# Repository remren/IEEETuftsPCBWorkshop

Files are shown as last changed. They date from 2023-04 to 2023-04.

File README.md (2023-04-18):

# IEEETuftsPCBWorkshop
An introductory PCB workshop for the Tufts IEEE club using KiCad 7.0. The basis for this workshop is making a keyboard PCB, following these guides: [Masterzen's Guide](https://www.masterzen.fr/2020/05/03/designing-a-keyboard-part-1/) and [ai03's Guide](https://wiki.ai03.com/books/pcb-design/page/pcb-guide-part-1---preparations)

By learning how to make this PCB, hopefully one will be able use knowledge for other personal or work projects!

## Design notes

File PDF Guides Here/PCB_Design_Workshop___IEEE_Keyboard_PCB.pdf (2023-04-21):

# PCB Design Workshop - Tufts IEEE Keyboard PCB

Remy Ren

March 2023

## 1 Before You Attend: DOWNLOAD KiCad 7.0

https://www.kicad.org/download/

1. Do this before coming to the workshop as it’s a 1 GB download for just the installer. KiCad is neat because it is OPEN SOURCE AND FREE!
2. Other PCB design tools exist, such as Altinum, EAGLE, EasyEDA, etc. but KiCad is a great starter.

## Optional: Git/Github Primer

Git/Github is a great solution for keeping track of files (version history), storing files, and collaboration.

If enough people want, I’ll go over a really basic primer on Git/Github using a command line interface (Terminal, Windows PowerShell, MobaXterm, etc.).

If you want to follow along or do this in your own time, the primer I’ll be giving can be found here:

https://bit.ly/Git-GithubPrimer

## 2 Starting Interface

1. Create a new folder in a place of your choice to put your project in. If you used Git/Github, make this new folder within where you cloned your repository.
2. In KiCad, click Create new blank project (CTRL+N), name it and save it to the folder you just made. We start with the Schematic Editor (CTRL+E) first.

1

3. We’ll need additional footprint libraries to use keyboard switches and USB-C ports. Either download the ZIP to each repository or add them as submodules in your repository:

https://github.com/ai03-2725/MX_Alps_Hybrid.githttps://github.com/ai03-2725/Type-C.pretty.githttps://github.com/ai03-2725/random-keyboard-parts.pretty.git

4. In Preferences → Manage Symbol Libraries and add the three libraries by clicking on the folder icon and adding the .lib file in the folders (may be nested within Schematic Folder ). Then, in Preferences → Manage Footprint Libraries, select all folders which have a .pretty at the end of its name.

## 3 Building the Schematic: Microcontroller Unit

1. We will be using the Atmega32U4 as our microcontroller of choice.
2. To add the component, press (A) or goto the right sidebar and select the op-amp icon. Give the interface some time to load!
3. Search atmega32u4 and select ATmega32U4-A (not -M as its pins are on the bottom of the package). Place it on the schematic by clicking within the space.
(a) The datasheet for this MCU: http://ww1.microchip.com/downloads/

en/devicedoc/atmel-7766-8-bit-avr-atmega16u4-32u4_datasheet.pdf (http://ww1.microchip.com/downloads/en/devicedoc/atmel-7766-8-bit-avr-atmega16u4-32u4_datasheet.pdf)
(b) We’ll be following this schematic to layout components for the MCU:

2

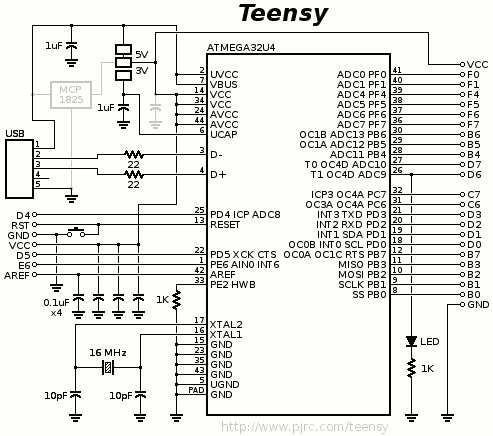
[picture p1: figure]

Figure 1: PJRC Teensy Schematic for the ATmega32U4-A

4. Let’s first add power/ground to the MCU. Press (P) or select the ground icon on the right sidebar, searching for: 5v. Select it and place it above the top of the MCU.
5. UVCC, VCC, AVCC all need to be connected to this +5V. To place wires and connect them, press (W) or the gray line icon on the right sidebar. Add another +5V component for VCC.
6. To place the ground, again press (P), search for GND and place it at the bottom of the MCU and cwonnect UGND, GND to GND.
7. The HWB/PE2 requires a pull-down resistor (needs to be connected to ground). Hit (A) and search for R or R Small (preferred). Add another ground and connect the resistor to it.

To exit any current action mode, press (ESC). If you want to rotate the component, press (R) while it is selected. To move a component, select and press (M).

8. Double-click on the R or R Small to edit its value and set it to 10k (discrepancy with Teensy schematic).
9. UCAP is the voltage regulator for the internal USB pins. It requires a 1µF (type 1u) capacitor according to the datasheet. Add a C Small to the pin and connect it to a new ground component.
10. AREF which is responsible for analog signals doesn’t need to be wired, so mouse over the pin and press (Q) to mark it with a cross.

3

11. Next, we’ll work with labels. These allow you to connect components together by name association instead of wires. There are two labels within KiCad: global or net class directive. Using either is OK in this demo, but if you were to use a multi-level/layer PCB, global is the preferred option.
12. To add a global label, press CTRL+L or click on the “tag” looking icon with an A inside.
13. Add a global label to XTAL1 naming it XTAL1, then do the same for XTAL2. To flip a component, press (X).
14. Add a global label the same way for D+, D-.
15. Next, we’ll be working to add an external clock for the MCU. Elsewhere on the board, place a global label for XTAL1, XTAL2.
16. The circuit for the external clock uses a 16MHz crystal oscillator (search Crystal GND24 small and two 22pF capacitors. Connect them to the global labels like this:

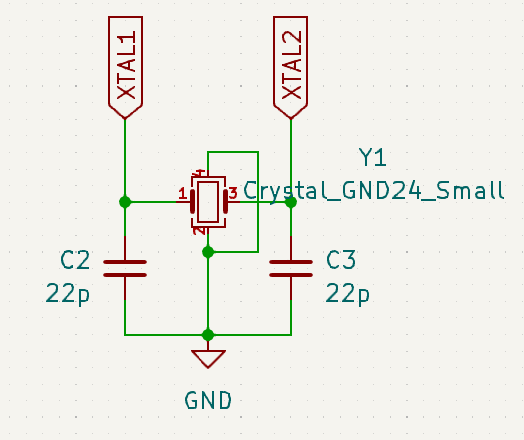
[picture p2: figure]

Figure 2: Schematic for XTAL

17. We need to add a set of decoupling capacitors for the MCU. The datasheet recommends a 0.1µF for each VCC pin (2xUVCC, 2xVCC, AVCC). One of the capacitors is shared between UVCC and VBUS instead of adding an additional one. We can make our schematic neater by using a +5V component to connect the capacitors like in the following:

4

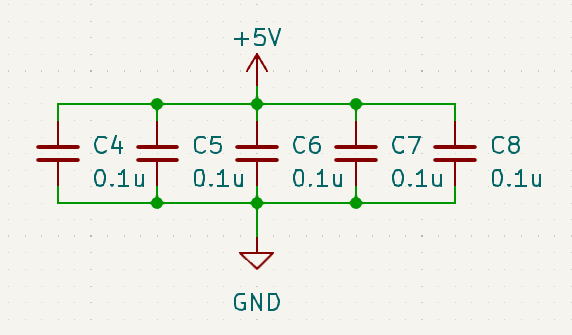
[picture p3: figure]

Figure 3: Schematic for Coupling Capacitors

Press (CTRL+C) and (CTRL+V) to copy/paste a component instead of entering it multiple times.

18. We will add a set of ISP header pins to access the MCU in event of catastrophic failure. This will allow us to reprogram the MCU with the Serial Peripheral Interface (SPI) and the ISP programming mode. (https://docs.qmk.fm/#/isp_flashing_guide)
(a) First, add a global label like we did earlier for MISO, MOSI, SCK. Connect them like this to the MCU:

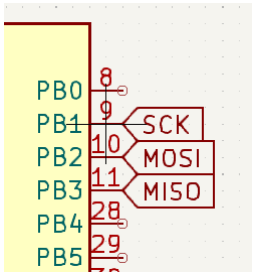
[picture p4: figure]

Figure 4: Global Labels for ISP to MCU

(b) Add a AVR-ISP-6 to the schematic. Connect a +5V to VCC, GND to GND. Create global labels for MISO, MOSI, SCK, RESET and connect them to their corresponding pins on the header.

5

19. Add a reset circuit to the schematic like so (SW Push and 10k res.):

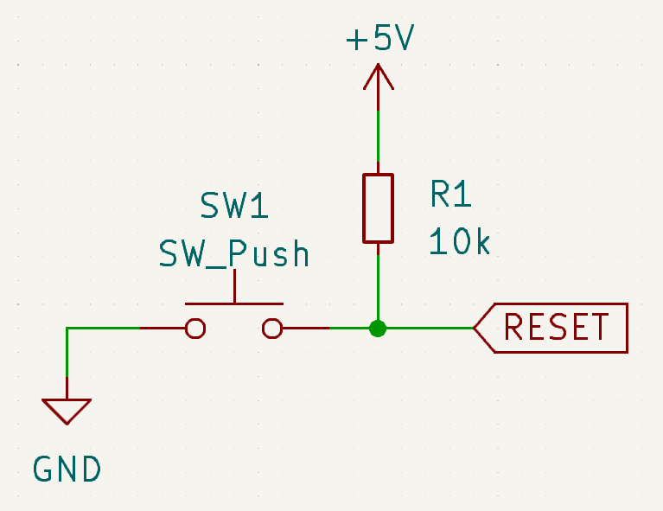
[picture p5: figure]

Figure 5: Basic Reset Schematic

Place a global label for reset likewise on the MCU.

20. Add a USB connector like so:

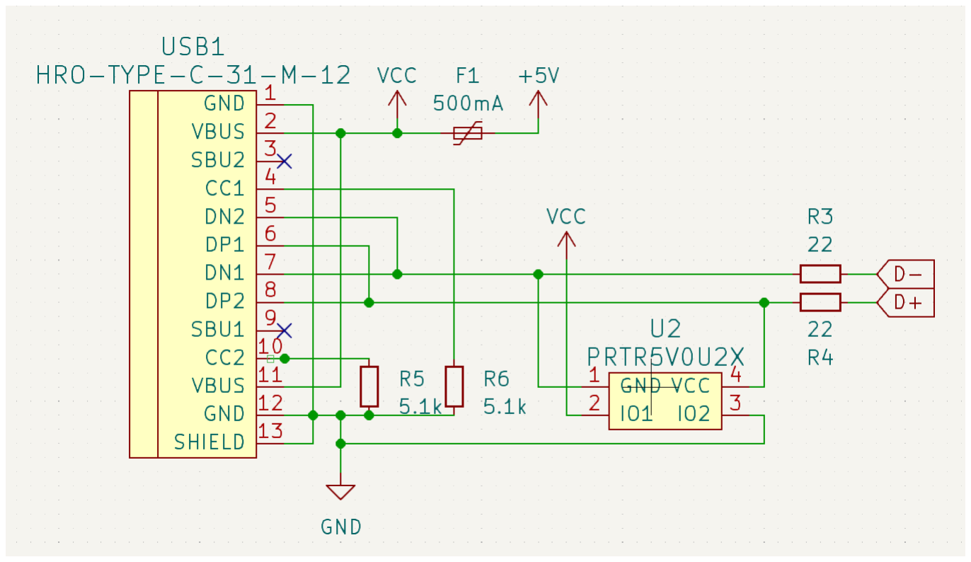
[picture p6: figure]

Figure 6: USB Connector Schematic

Note that F1 is a Polyfuse Small and the PRTR5V0U2X (ESD protection) is from aio3’s submodules, not the one from KiCad’s default libraries.

6

For more details as to why these components were chosen, see: Masterzen’s Guide Pt. 1 (https://www.masterzen.fr/2020/05/03/designing-a-keyboard-part-1/)

21. Congratulations! You’re now done with the MCU! You should have a schematic like this:

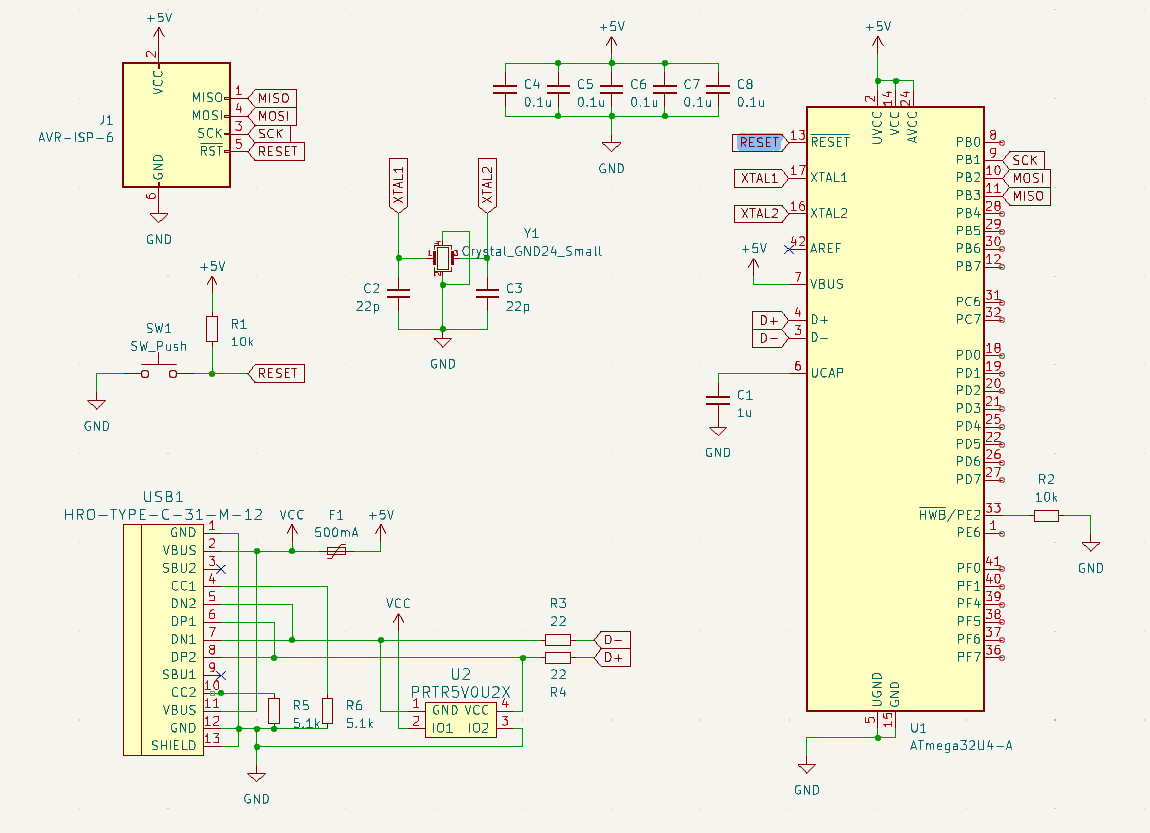
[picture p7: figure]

Figure 7: Current MCU Schematic

Whew! That was a lot! But we’re not done just yet!

## 4 Building the Schematic: Switch Matrices

For this workshop, we’ll just be constructing a simple 2x2 macropad. If you’re looking to create an entire keyboard, the process is not very different, just a bit more time consuming. If you wish to create an entire keyboard, follow: Masterzen’s Guide Pt. 2 (https://www.masterzen.fr/2020/05/25/designing-a-keyboard-part2/)

1. To make a basic cell of the matrix, create this circuit. We will not be assigning values yet:

7

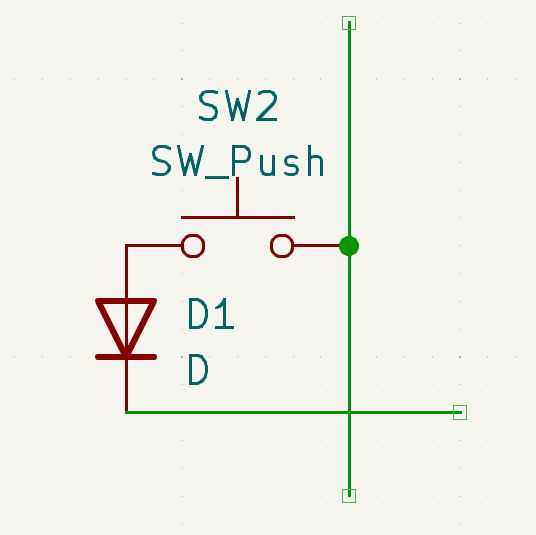
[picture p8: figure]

Figure 8: Keyboard Matrix Cell

To terminate wires without connecting it to a component, press (K).

2. Now copy the cell and paste into an arrangement like this:

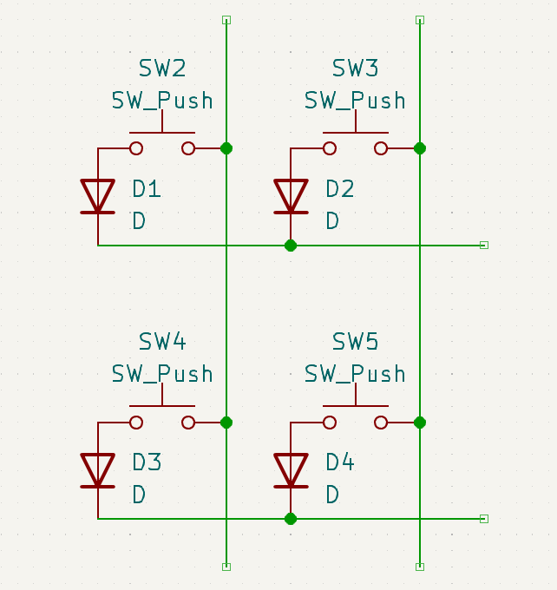
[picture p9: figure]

Figure 9: Keyboard Matrix

3. Add the global labels col0, col1, row0, row1 to the matrix as shown.

8

You will need to delete the extraneous wires:

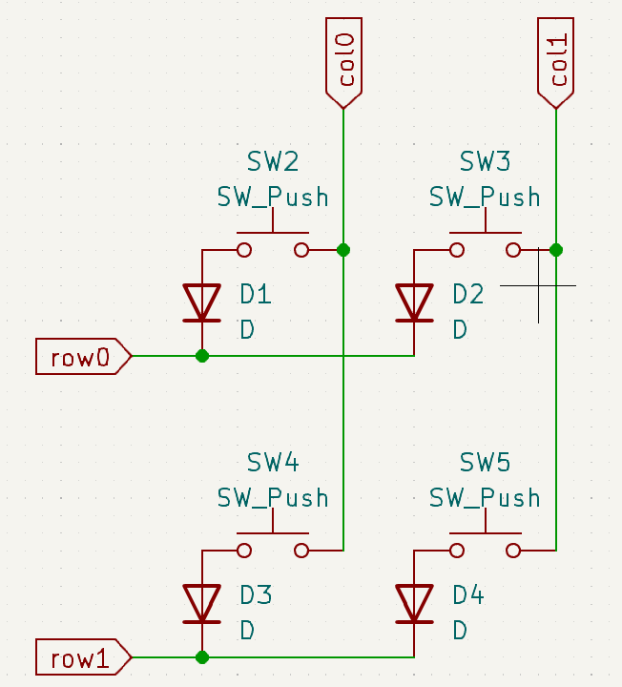
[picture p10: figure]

Figure 10: Keyboard Matrix Labeled

4. Attach corresponding global labels col0, col1, row0, row1 to the MCU pins PB4, PB5, PB6, PD7. Note, the last one is at PD7. For all the other unused pins, you can mark them with a cross via (Q). Super congrats! You’re now done with the schematic... but there’s more afterwards!

9

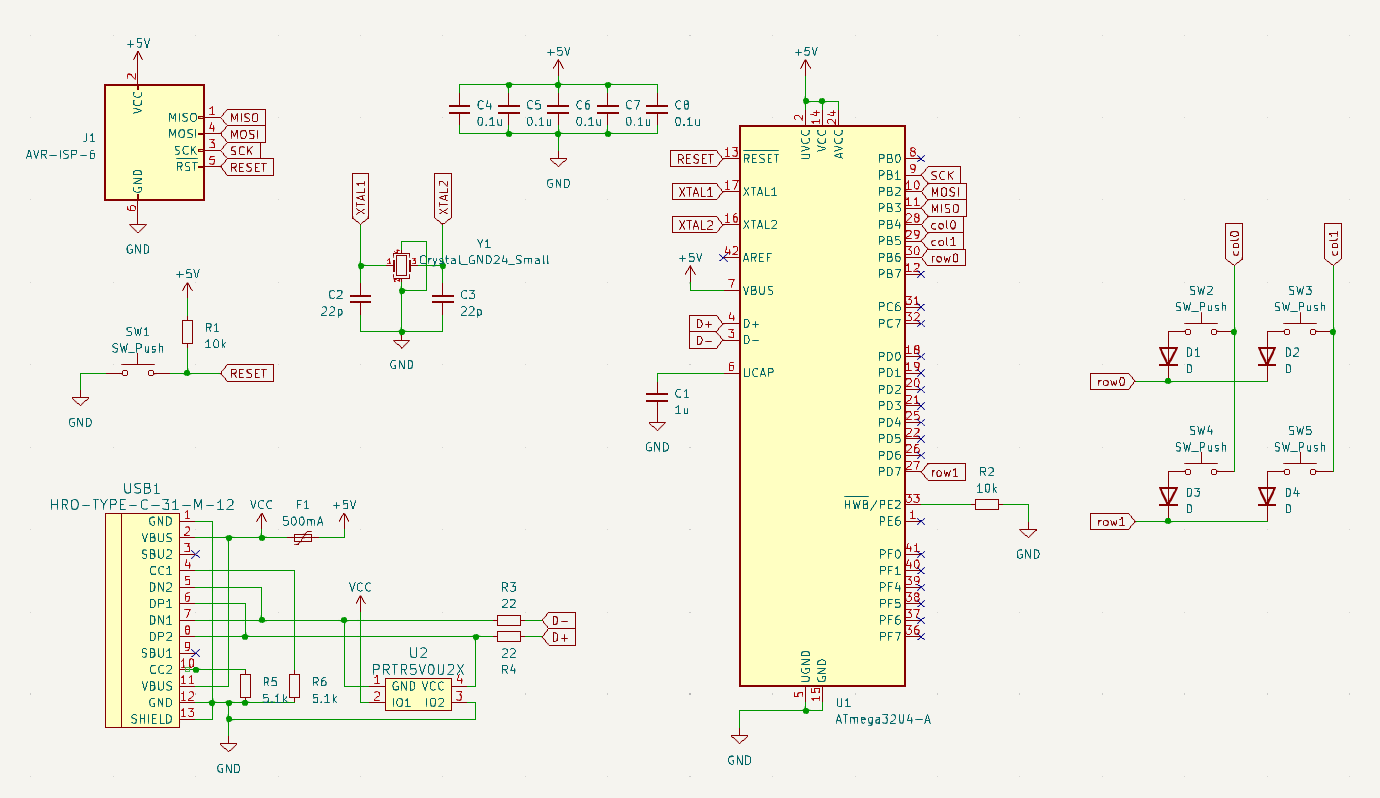
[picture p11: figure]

Figure 11: Completed Keyboard Schematic

## 5 Assigning Footprints

KiCad now knows about the circuit you laid down! However, to turn this into a PCB, it doesn’t yet know how to translate the components into their actual physical counterparts. To do this, we need to assign the footprints.

1. To start assigning footprints, use Run footprint assignment tool in either Tools or here on the hotbar:

For context, most of the text in footprint names indicate dimensions:

10

2. Assign the footprints according to this table:
Components | Footprint
Capacitors | Capacitor SMD:C 0805 2012Metric Pad1.15x1.40mm HandSolder
Diodes | Diode SMD:D SOD-123
Fuse | Fuse:Fuse 1206 3216Metric Pad1.42x1.75mm HandSolder
ISP Header | random-keyboard-parts:Reset Pretty-Mask
Resistors | Resistor SMD:R 0805 2012Metric Pad1.20x1.40mm HandSolder
Reset Push Switch (SW1) | Button Switch SMD:SW SPST SKQG WithStem
Keyboard Switches (SW...) | MX Alps Hybrid:MX-1U-NoLED
ATmega32U4-A | Package QFP:TQFP-44 10x10mm P0.8mm
PRTR5V0U2X | random-keyboard-parts:SOT143B
USB Type-C Connector (HRO...) | Type-C:HRO-TYPE-C-31-M-12-HandSoldering
Crystal Resonator | Crystal:Crystal SMD 3225-4Pin 3.2x2.5mm HandSoldering

Once done, press Apply, Save Schematic & Continue. If you haven’t already,
save your project!

## 6 Creating the PCB: Arrangements

Navigate to the PCB Editor (CTRL+P) in the main menu window. Now, press Update PCB with changes made to schematic (F8). This will spit everything out in the PCB schematic in one big cluster. To create the PCB, we’ll first make various arrangements.

1. We’ll want to set custom grid snapping to make placing components easy (Size X/Y: 0.79375mm, Grid 1: User grid, Grid 2: 0.1270 mm (0.0050 in)

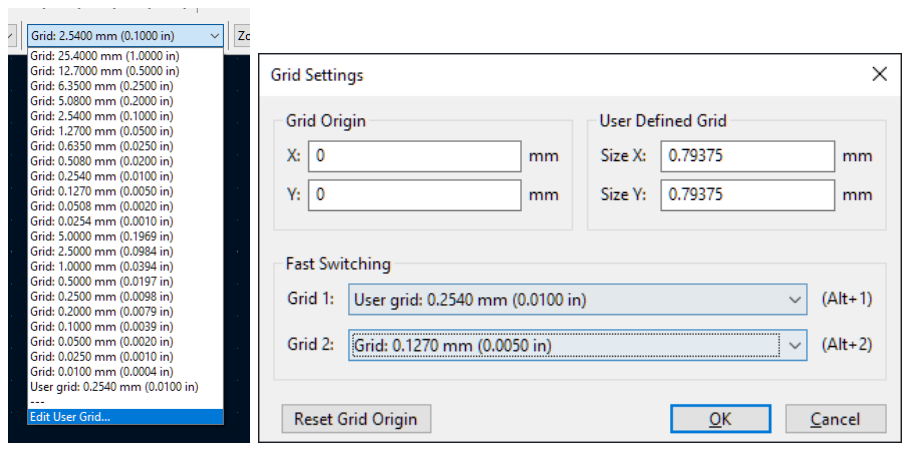
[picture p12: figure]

2. While in the PCB Editor, some hotkeys function may change: (M) move,
(R) rotate, (X) create traces, (V) create a via (“Through-hole”, (CTRL+F) find comp.

11

3. The blue lines aka “rats nest” represents all traces from the schematic. To make the actual traces, press (X). If a trace can’t connect, it’s likely due to KiCad trying to avoid an short.
4. By default, KiCad has two layer PCBs, where there’s a front (F.Cu) and back copper (B.Cu) layer. Masterzen’s Guide Pt.2 (https://www.masterzen.fr/2020/05/25/designing-a-keyboard-part2/) contains a concise summary of these layers:
Components | Type | Usage
F./B.Cu | Technical Pair | Denotes copper trace layers
F./B.Adhesive | Tech. Pair | Denotes adhesive layers to hold SMDs to PCB before soldering
F./B.Paste | Tech. Pair | Defines mask to place solder for reflow soldering
F./B.Silkscreen | Tech. Pair | Denotes where components are drawn
F./B.Mask | Tech. Pair | Defines areas w/no solder mask e.g. component pads
F./B.Courtyard | Tech. Pair | Shows how much physical space a component takes
F./B.Fab | Tech. Pair | Documentation for manufacturing
Edge.Cuts | Independent | Defines a safe margin for PCB edge cuts
User.Drawings/Comments | Optional | Can be used for instructions, drawings. Some footprints may use them.
User.Eco1/2 | Optional | User specific, never used in footprints
5. Next, drag and select all the SMD component footprints to the back copper
layer. To do this, press (F) after selecting them.

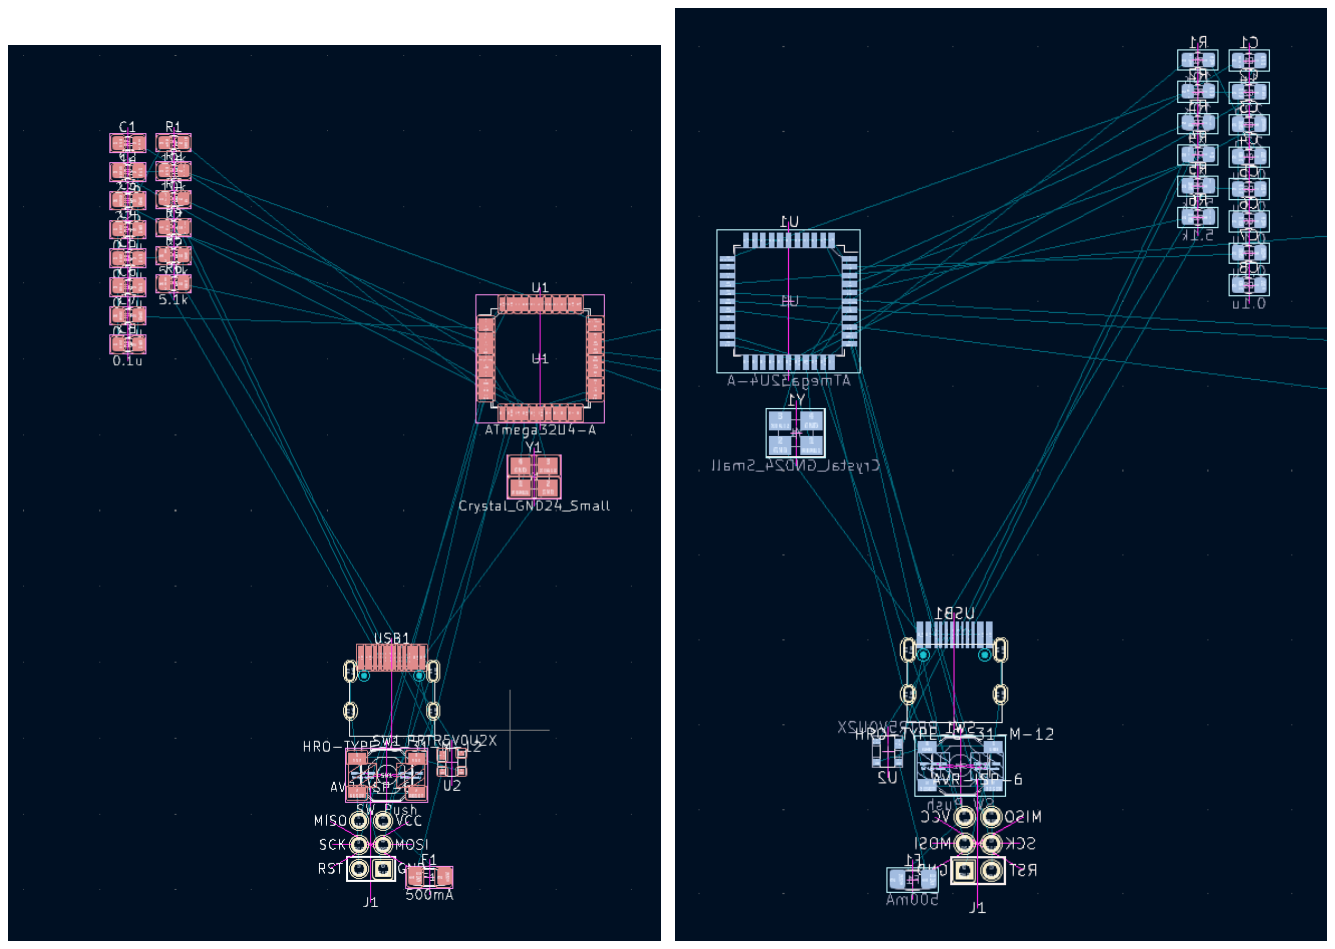
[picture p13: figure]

Figure 12: flip

6. While in Grid 1 (ALT+1), move the keyboard switches in this arrangement (overlapping outlines):

12

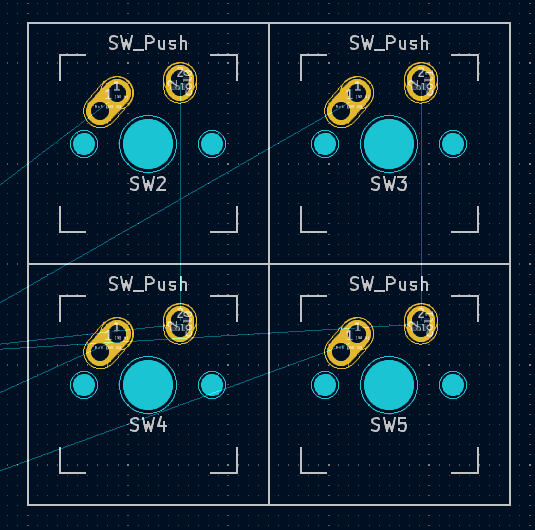
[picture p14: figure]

Figure 13: Arranging Switches

Make sure the ordering matches the schematic’s (SW2, SW3, SW4, SW5).

7. While still in Grid 1, move the diodes to these positions:

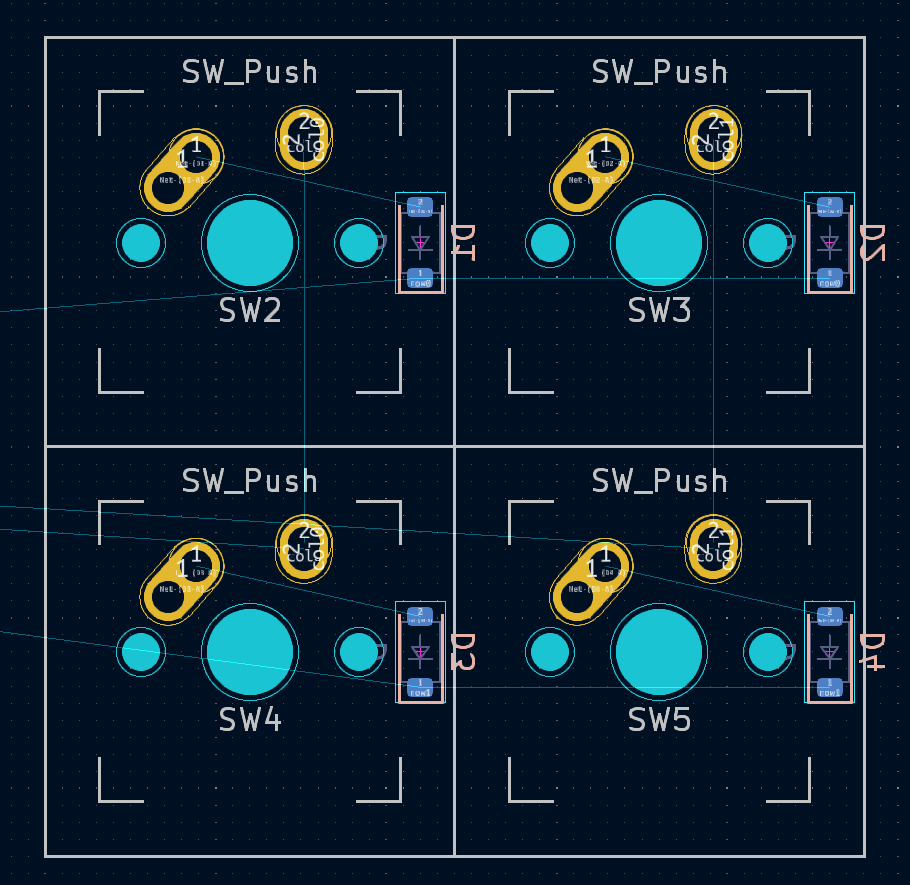
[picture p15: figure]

Figure 14: Note the order of the diodes follow the schematic (flipped).

8. If you zoom into components enough, you can also see which pins or labels they connect to. Move the capacitors for the MCU so that they are close to the pins they connect to and the rat traces are neater. Note, these are tentative layouts. When routing (placing traces), components may need to be moved to avoid conflicts.

13

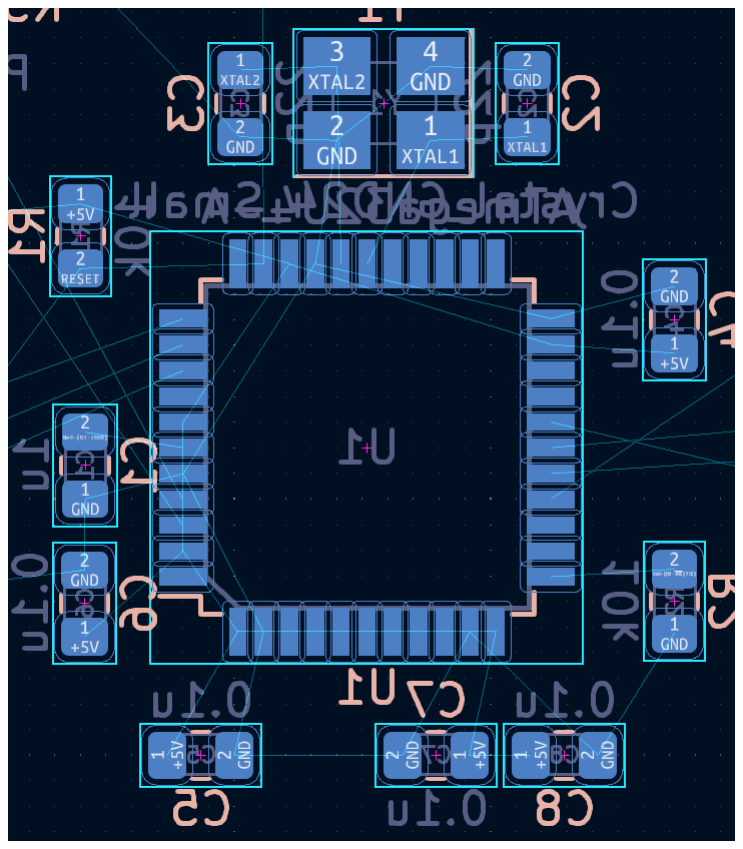
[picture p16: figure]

Figure 15: Components do not have to exactly match this arrangement.

9. For now, not all the components have to be arranged. We’ll draw out the edge cut out line next. Select Edge.Cuts on the right sidebar.
10. First, round one of the corners of the switches using the arc tool on the right sidebar (CTRL+SHIFT+A):

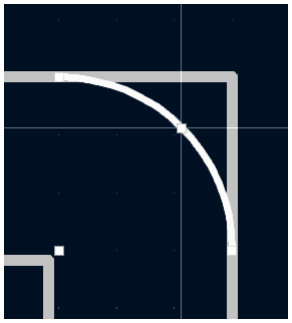
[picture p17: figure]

Figure 16: Note the order of the diodes follow the schematic (flipped).

Create the rest of the lines using straight lines. You can copy the lines

14 and overlay them for a longer edge. If you have trouble seeing the outline from Edge.Cuts, you may have to recolor the layer. This can be done by double-clicking the color, where it might prompt you to create a new theme. In preferences, go to PCB Editor → Colors, create a new theme and edit Edge.Cuts to a color you like.

You can also hide the User.Drawings layer to get a better view. Make sure that your lines in Edge.Cuts are all properly aligned and make a shape with no gaps.

11. Afterwards, position the remaining components within the area defined by Edge.Cuts. Try to keep the components related to the USB-C connector parallel as we will have to route a differential pair later. You should end up with a result roughly like this:

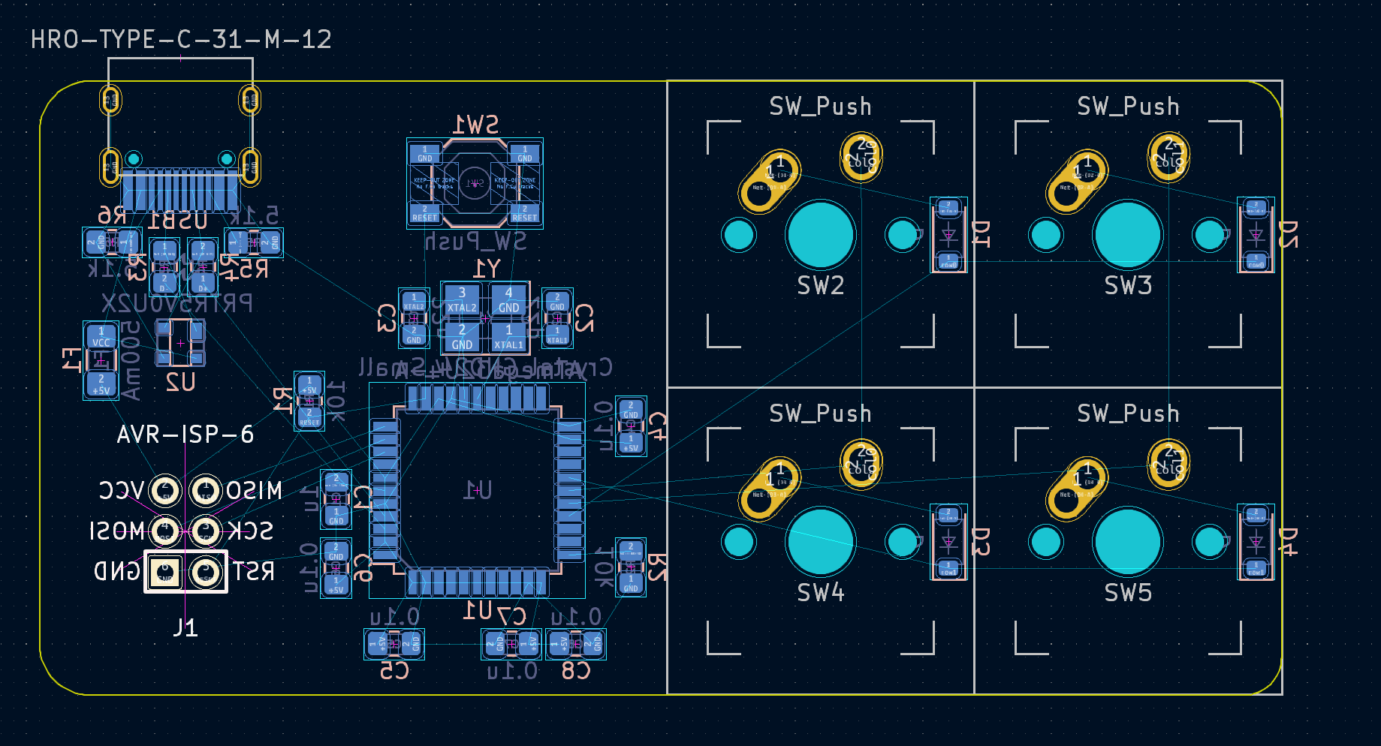
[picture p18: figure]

Figure 17: Tentative layout, may change in routing.

12. At this stage, we can take a good look at our progress, but now in 3D! Go to View → 3D Viewer (ALT+3) to see the model.
13. You may have noticed that the USB-C connector only has its pads and doesn’t have a model for the actual connector. To get the 3D model, double click the component in the PCB Editor, then the Footprint Properties window should appear.
14. Click the tab 3D Models and click on the “+” symbol.

15

15. Navigate to where you downloaded ai03’s PCB footprints and find the folder “Type-C.pretty” and select the .step file. If you have SolidWorks installed, this might show up as a CAD file.
16. Apply the following transformation:
Rotation: X = -90.00◦
, Offset: X = -4.45mm
17. WE’RE ALMOST THERE! Now time for the final stage, ROUTING!

## 7 Creating the PCB: Routing

Routing is where we’ll connect components via traces. The hotkeys of interest are: (X) make a trace, (V) make a via. Vias allow you to connect traces on one layer to the other (front/back) in series by creating a copper-coated hole.

You will want to minimize the number of vias you use as each one will add inductance to the trace. In addition, for the differential pair traces, it’s generally recommended to not use vias in their routes.

(Interested in routing fundamentals? See: Masterzen’s Guide Pt.3) (https://www.masterzen.fr/2020/10/20/designing-a-keyboard-part3/)

1. Make sure you’re on one of the copper layers (F/B.Cu) first. You may also want to switch to Grid 2 for routing.
2. First, add these traces to the USB-C connector:

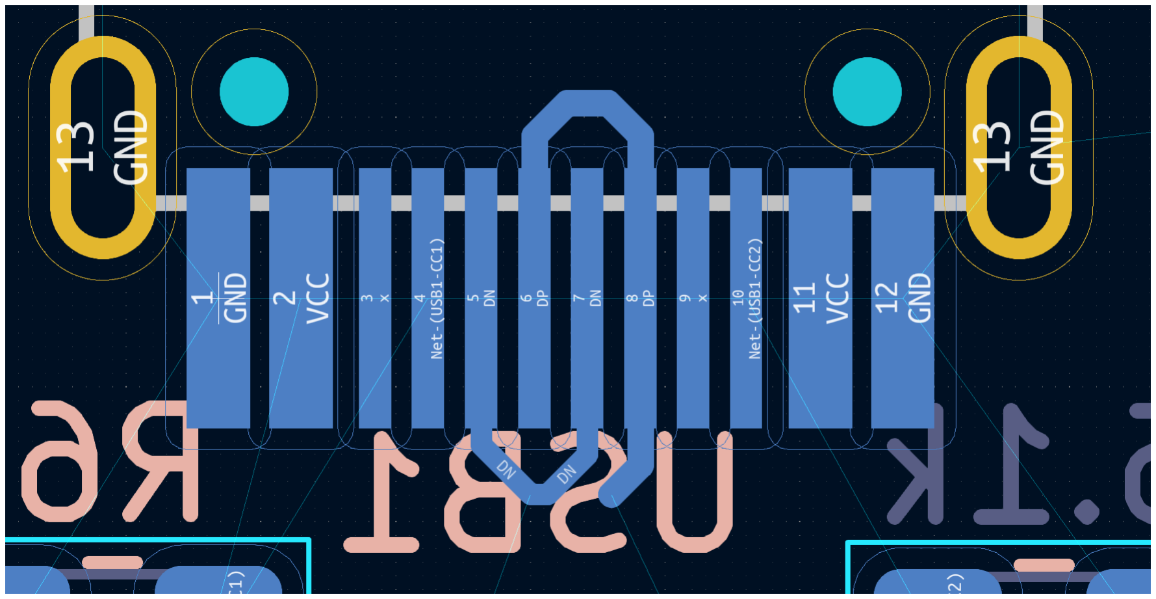
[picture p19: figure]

Figure 18: Note that the end of the traces on the left is triangular.

3. A helpful tip, if you press (U) while selecting a trace, then press it a few more times, it will select the entire trace if you need to delete it.
4. Now, we want to route the differential pair. Find this in Route our press (6). You might have an error appear about the names of the nets. To fix this, add global labels in the Schematic Editor to the data lines:

16

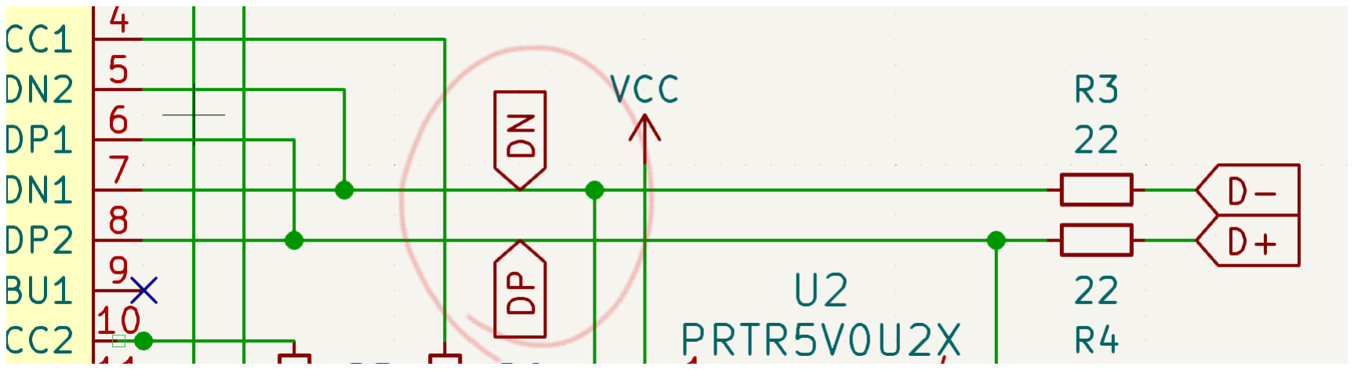
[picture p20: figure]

Figure 19: Placing DP, DN on the Schematic Editor

5. Make sure to update the PCB from the schematic afterwards (F8).
6. There are a couple of rules when it comes to routing differential pairs. Due to time constraints we will unfortunately we not be following those rules to a tee (see Masterzen’s Guide Pt.3 (https://www.masterzen.fr/2020/10/20/designing-a-keyboard-part3/) if you’re interested). Do what you can to get the differential pairs to properly route:

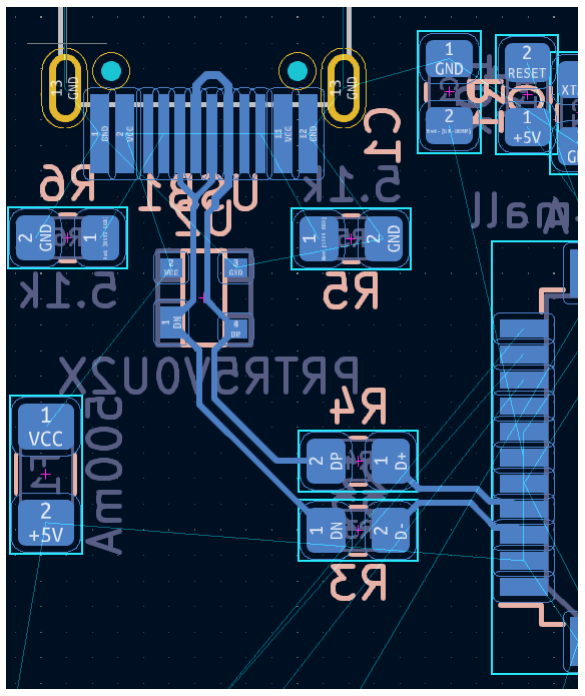
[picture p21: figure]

Figure 20: Example of differential pair routing. Note the attempt at symmetry.

7. Next, route the switches. Unfortunately, the default library in KiCad does not indicate which way the SW Push opens or closes. If you cannot route the vias (through-holes) from the switches to the diodes, you may need to flip its corresponding SW Push in the schematic editor.

17

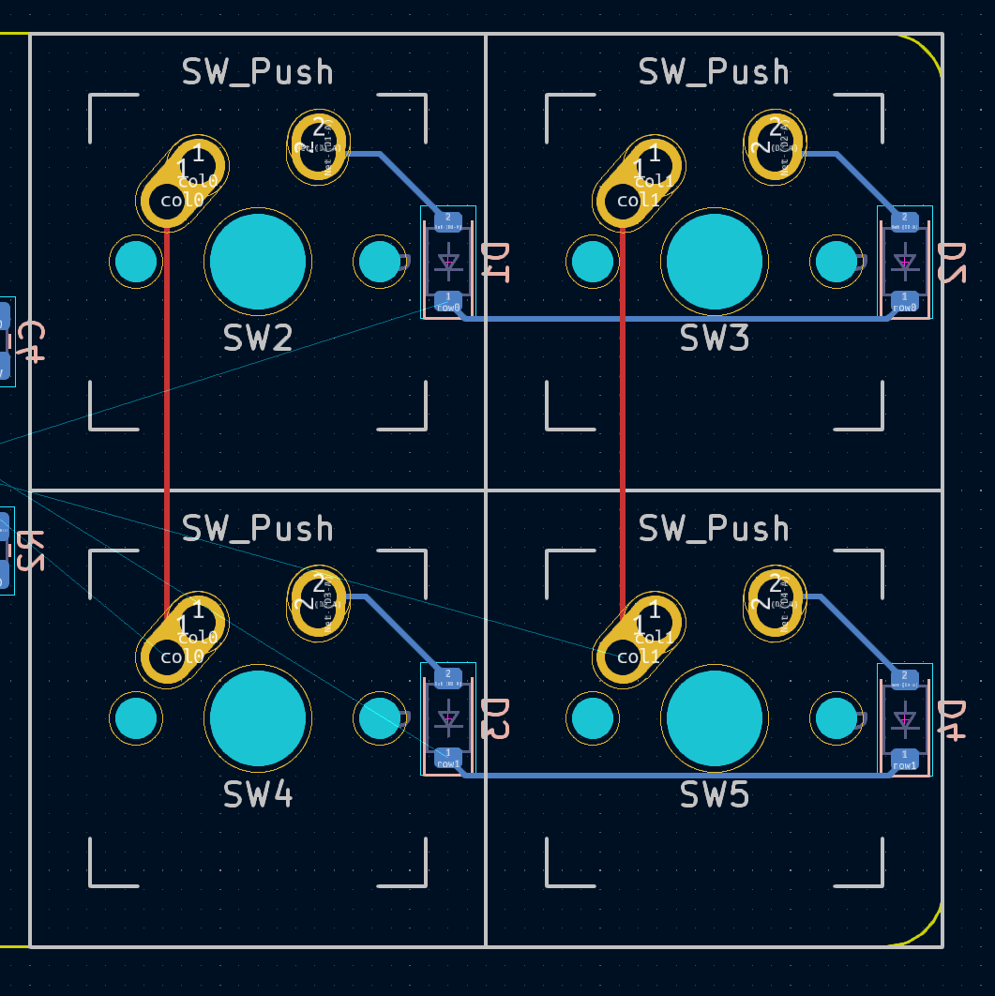
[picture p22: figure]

Figure 21: Switch Matrix Routing

8. Note that routing is will take a lot of time! It’s really more like a puzzle so it is a skill that takes practice. Don’t worry if you end up with situations that are impossible to continue, just keep trying!
9. Once you think you’re done with routing, that everything is connected to each other, click on: Show the design rules checker window. Then click on: Run PRC

Figure 22: Note the order of the diodes follow the schematic (flipped).

10. Fix any unconnected errors and run the checker again. There are some odd errors with the USB-C tolerances and the vias on the switches. You can ignore those errors for now, but you may need to check/fix these issues if you wish to put this PCB to fabrication.
11. If we run into time issues, you can download my PCB that has the traces finished to move onto the next part.

18

Note that we are missing some additional components that are used for protecting the circuit and ensuring a stable output. Again, please check out Masterzen’s Guide Pt.3 (https://www.masterzen.fr/2020/10/20/designing-a-keyboard-part3/) if you are interested.

12. You should end up a result somewhat like this:

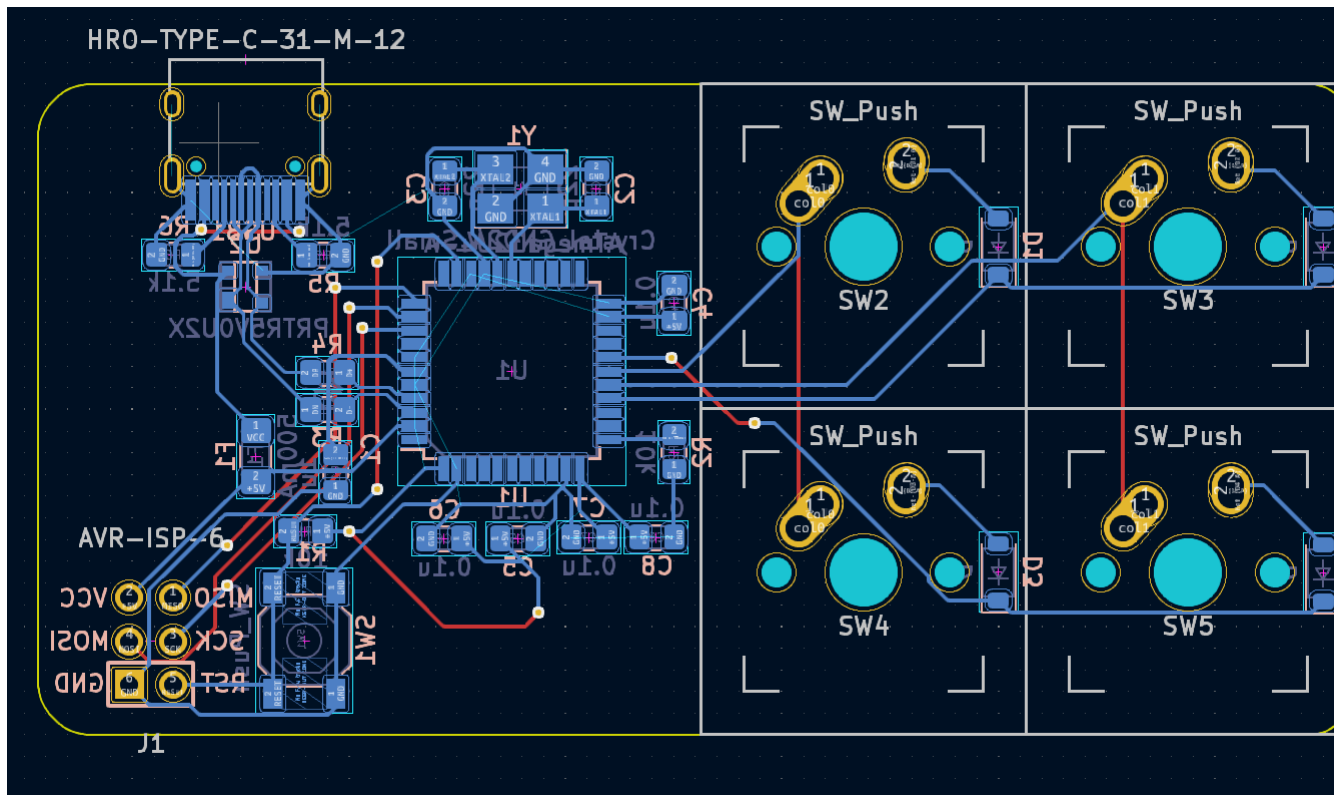
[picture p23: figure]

Figure 23: Example Complete Routing (might be with errors).

## 8 Creating the PCB: Ground Fills and Extras

1. Next, we need to create a ground fill. There are a couple of reasons to do this, especially for high-speed circuits. For actual reasons, again check out Masterzen’s Guide Pt.3. (https://www.masterzen.fr/2020/10/20/designing-a-keyboard-part3/)
2. To do add a filled zone press (CTRL+SHIFT+Z) or its corresponding icon in the right sidebar (“blue tetris block with a gray line”).
3. Grid 1 would probably be the best option to outline the circuit area. Note that this is likely not the best way to make the ground fill for this circuit. In Masterzen’s Guide Pt.3, (https://www.masterzen.fr/2020/10/20/designing-a-keyboard-part3/) it goes much more into detail about methodologies behind why or how to create a proper ground fill.

19

4. Make sure that in the new window, “Copper Zone Properties”, that only on B.Cu is selected. Then click on the GND option and click OK.
5. Make a rectangle that outlines the left half of the board then press (B) to fill the entire zone:

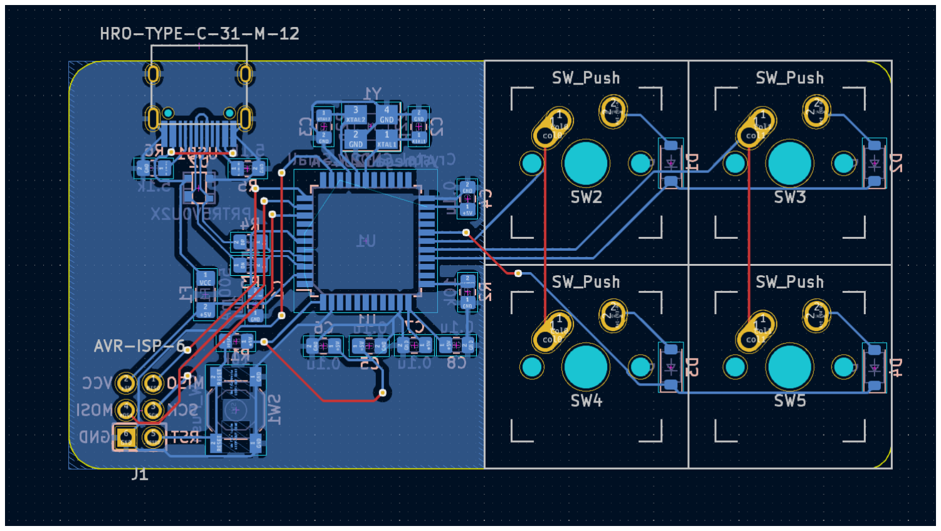
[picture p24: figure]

Figure 24: The filled zones are all in a transparent blue (B.Cu)

6. Check if there are any errors with the board by running DRC again. If you run into a thermal relief error, you may just need to add a standalone via someplace on the board.
7. No errors anymore? CONGRATULATIONS! Pat yourself on the back because you have finished creating a PCB! Be sure to iterate and improve the design or retry routing if you are unsatisfied with the result.

## 9 Final Steps: Gerber Files and Fabrication

1. To be continued!
2. For actual fabrication, I recommend Masterzen’s Guide Pt.4. (https://www.masterzen.fr/2020/12/16/desiging-a-keyboard-part4/) After fabricating the PCB though, it seems that there hasn’t been much progress on their guide. Note, from the comments, there also may be additional errors such as the confusion between a standalone crystal or crystal oscillator unit.

## 10 References

This workshop wouldn’t have been possible without these guides!

20

Masterzen’s Guide (https://www.masterzen.fr/2020/05/03/designing-a-keyboard-part-1/) - Incredible resource with more EE aspects to the design. aio3’s Guide (https://wiki.ai03.com/books/pcb-design/chapter/pcb-designer-guide) - Great primer, uses some simpler components, but useful nontheless.

21

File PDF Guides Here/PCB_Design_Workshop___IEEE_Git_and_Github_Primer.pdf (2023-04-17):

# PCB Design Workshop - IEEE Git and Github Primer

Remy Ren

March 2023

## Optional: Git/Github Primer (15-20 Mins.)

Git/Github is a great solution for keeping track of files (version history), storing files, and collaboration.

If enough people want, I’ll go over a really basic primer on Git/Github using a command line interface (Terminal, Windows PowerShell, MobaXterm, etc.).

SHOUTOUTS TO TOM LYONS YO.

1. Create a Github account if you haven’t already.
2. Create a new repository and name it. All other choices are optional. You should be on the Quick Setup page. Keep this tab in the background!
3. Open your command line interface (CLI) of choice. To access your repository, we will be using SSH keys as our method of choice. Don’t worry! Copy/paste is your best friend and just be careful!
4. The setup is the same either locally or in your Halligan login. For today, as we’ll be working on files locally, doing this locally might be best.
5. Enter the command: ssh-keygen
6. You should be prompted to “Enter file in which to save the key (some address)” Keep track of this address!
(a) This directory may be hidden depending on your CLI. To view them later, you can enter this: ls -la1
7. Don’t type anything and hit enter for both the previous “file” prompt.
8. Again, don’t type anything and hit enter for both “passphrase” prompts.
9. Navigate to the address the key is stored at (check your CLI output at
step 6).

1

10. Enter the command: cat id rsa.pub
Copy the entire text from ssh-rsa.pub to your computer name. This is your public key!
11. In Github, navigate to Settings → SSH and GPG keys.
12. Click New SSH Key, give it a relevant title (“laptop”, “Halligan”), paste your saved RSA public key and add it.
13. In Github, go back to your new repository. Click on the green Code button, click on SSH and copy the SSH link.
14. In your CLI, find or create a directory you want to save your project in.
(a) I recommend: Documents → KiCad, then making a new folder called “Tufts Projects”.
15. In this directory, e.g. “Tufts Projects”, use the following command with your copied SSH link for the underscore:

git clone

For example, with an SSH link: git@github.com:remren/IEEETuftsPCBWorkshop.git, in the CLI enter: git clone git@github.com:remren/IEEETuftsPCBWorkshop.git

16. Any time you want to check the status of what Git is doing, use the
following:

git status

17. Once you’ve made changes to the directory you’re working in, you want to use the command:

git add .

This adds all the files in the directory to a branch. The “.” is to state all files in the folder.

18. If you want to commit your changes to the branch, use the command:

git commit -m "type your commit message"

19. Once you feel your commited changes are all set, to upload the changes to the repository in Github, use the command:

git push

20. Now you’re all set to use Git and Github! Have fun and enjoy!

2

21. ADDITIONAL: If your local version is behind first check its status using “git status”. To update your local version to the version in the repository, use:

git pull

22. OPTIONAL: To add a submodule (some other repository) from Github into your repository/directory, copy the HTTPS link from the desired Github repository, then do the following:

git submodule add https://github.com/project/project.git

23. OPTIONAL: If you used git pull, but you’ve included submodules, they might have not updated their contents. To force the update, use: git submodule update --init --recursive

3

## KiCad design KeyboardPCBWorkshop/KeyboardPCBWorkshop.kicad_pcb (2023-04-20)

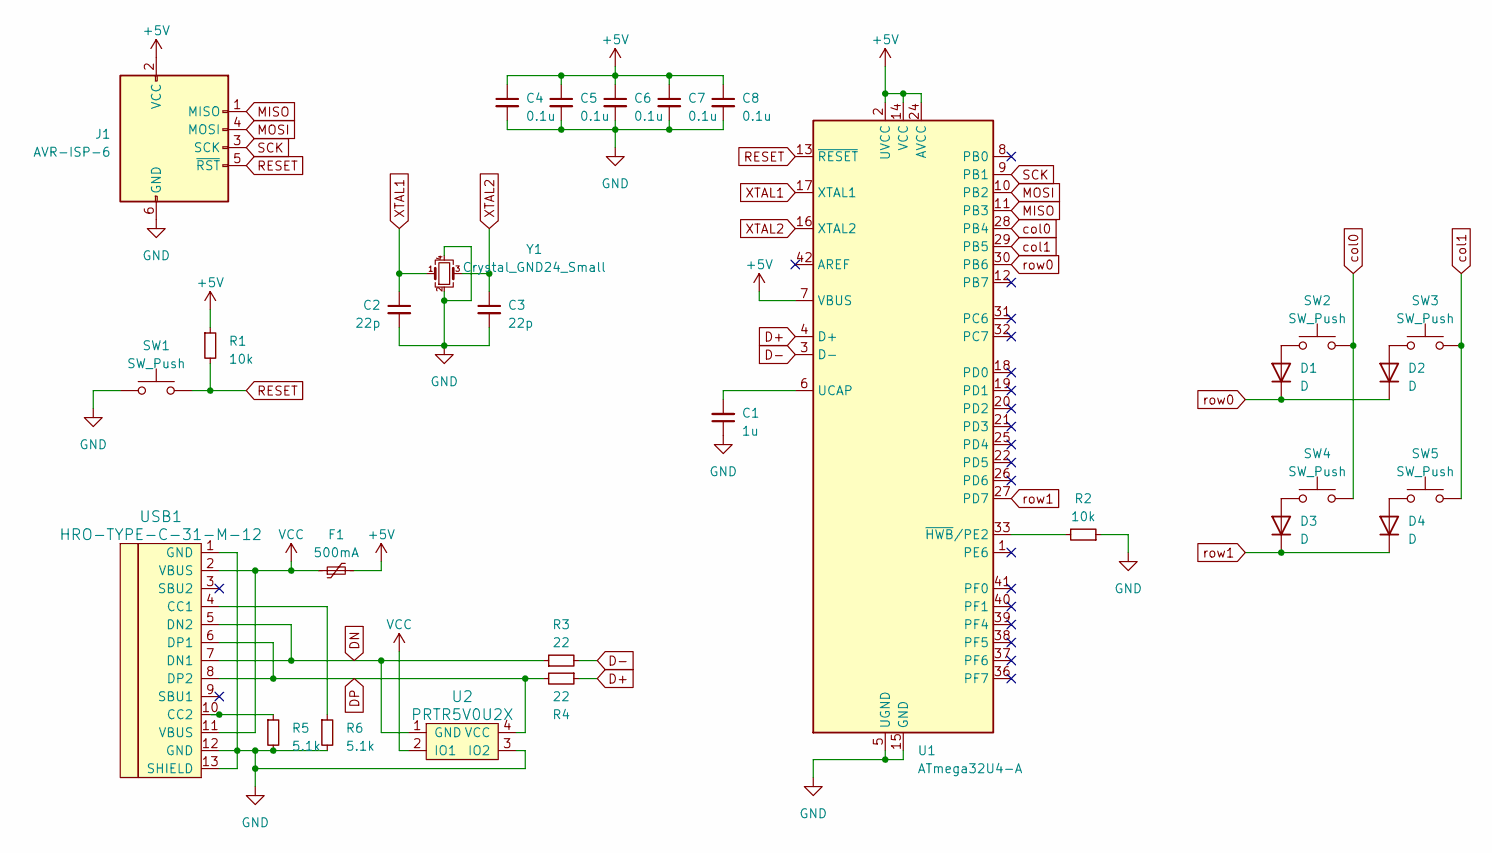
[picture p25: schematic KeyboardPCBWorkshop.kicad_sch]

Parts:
C1: 1u; C_0805_2012Metric_Pad1.18x1.45mm_HandSolder
C2, C3: 22p; C_0805_2012Metric_Pad1.18x1.45mm_HandSolder
C4, C5, C6, C7, C8: 0.1u; C_0805_2012Metric_Pad1.18x1.45mm_HandSolder
D1, D2, D3, D4: D; D_SOD-123
F1: 500mA; Fuse_1206_3216Metric_Pad1.42x1.75mm_HandSolder
J1: AVR-ISP-6; Reset_Pretty-Mask
R1, R2: 10k; R_0805_2012Metric_Pad1.20x1.40mm_HandSolder
R3, R4: 22; R_0805_2012Metric_Pad1.20x1.40mm_HandSolder
R5, R6: 5.1k; R_0805_2012Metric_Pad1.20x1.40mm_HandSolder
SW1: SW_Push; SW_SPST_SKQG_WithStem
SW2, SW3, SW4, SW5: SW_Push; MX-1U-NoLED
U1: ATmega32U4-A; TQFP-44_10x10mm_P0.8mm
U2: PRTR5V0U2X; SOT143B
USB1: HRO-TYPE-C-31-M-12; HRO-TYPE-C-31-M-12-HandSoldering
Y1: Crystal_GND24_Small; Crystal_SMD_3225-4Pin_3.2x2.5mm_HandSoldering

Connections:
+5V: C4.1, C5.1, C6.1, C7.1, C8.1, F1.2, J1.2 (VCC), R1.1, U1.2 (UVCC), U1.7 (VBUS), U1.14 (VCC), U1.24 (AVCC), U1.34 (VCC), U1.44 (AVCC)
D+: R4.1, U1.4 (D+)
D-: R3.2, U1.3 (D-)
DN: R3.1, U2.1 (GND), USB1.5 (DN2), USB1.7 (DN1)
DP: R4.2, U2.4 (VCC), USB1.6 (DP1), USB1.8 (DP2)
GND: C1.1, C2.2, C3.2, C4.2, C5.2, C6.2, C7.2, C8.2, J1.6 (GND), R2.1, R5.2, R6.2, SW1.1, U1.5 (UGND), U1.15 (GND), U1.23 (GND), U1.35 (GND), U1.43 (GND), U2.3 (IO2), USB1.1 (GND), USB1.12 (GND), USB1.13 (SHIELD), Y1.2, Y1.4
MISO: J1.1 (MISO), U1.11 (PB3)
MOSI: J1.4 (MOSI), U1.10 (PB2)
unnamed: D1.2 (A), SW2.2
unnamed: D2.2 (A), SW3.2
unnamed: D3.2 (A), SW4.2
unnamed: D4.2 (A), SW5.2
unnamed: C1.2, U1.6 (UCAP)
unnamed: R2.2, U1.33 (~HWB/PE2)
unnamed: R6.1, USB1.4 (CC1)
unnamed: R5.1, USB1.10 (CC2)
RESET: J1.5 (~RST), R1.2, SW1.2, U1.13 (~RESET)
SCK: J1.3 (SCK), U1.9 (PB1)
VCC: F1.1, U2.2 (IO1), USB1.2 (VBUS), USB1.11 (VBUS)
XTAL1: C2.1, U1.17 (XTAL1), Y1.1
XTAL2: C3.1, U1.16 (XTAL2), Y1.3
col0: SW2.1, SW4.1, U1.28 (PB4)
col1: SW3.1, SW5.1, U1.29 (PB5)
row0: D1.1 (K), D2.1 (K), U1.30 (PB6)
row1: D3.1 (K), D4.1 (K), U1.27 (PD7)

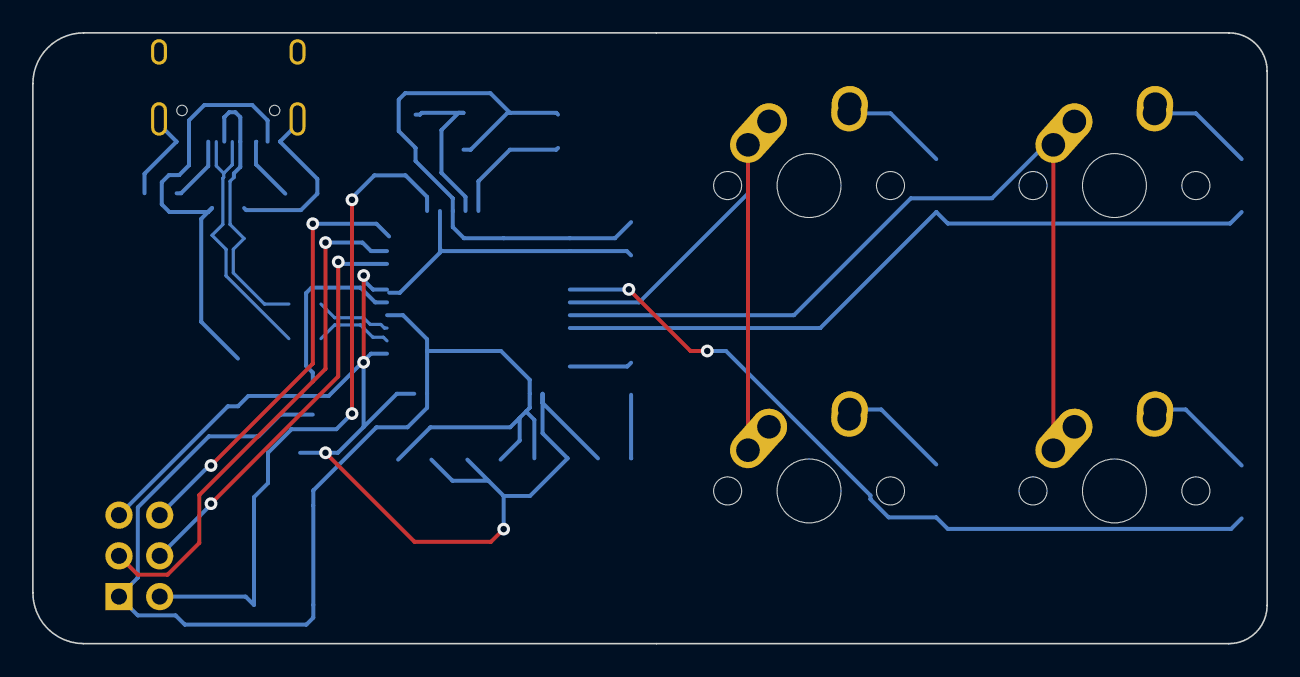
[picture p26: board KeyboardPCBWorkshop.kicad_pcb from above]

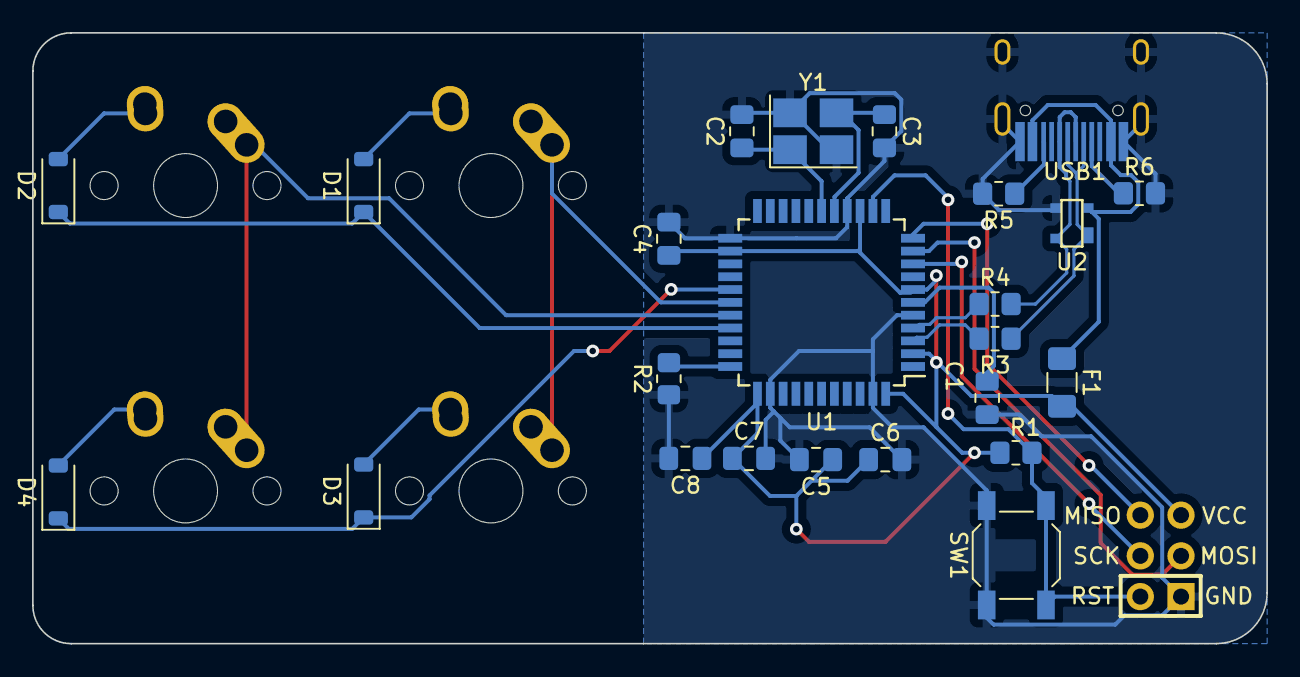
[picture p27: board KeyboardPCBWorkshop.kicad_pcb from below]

Board: 2 copper layers, 77.0 x 38.1 mm, 29 parts (25 on the bottom side), 25 nets.

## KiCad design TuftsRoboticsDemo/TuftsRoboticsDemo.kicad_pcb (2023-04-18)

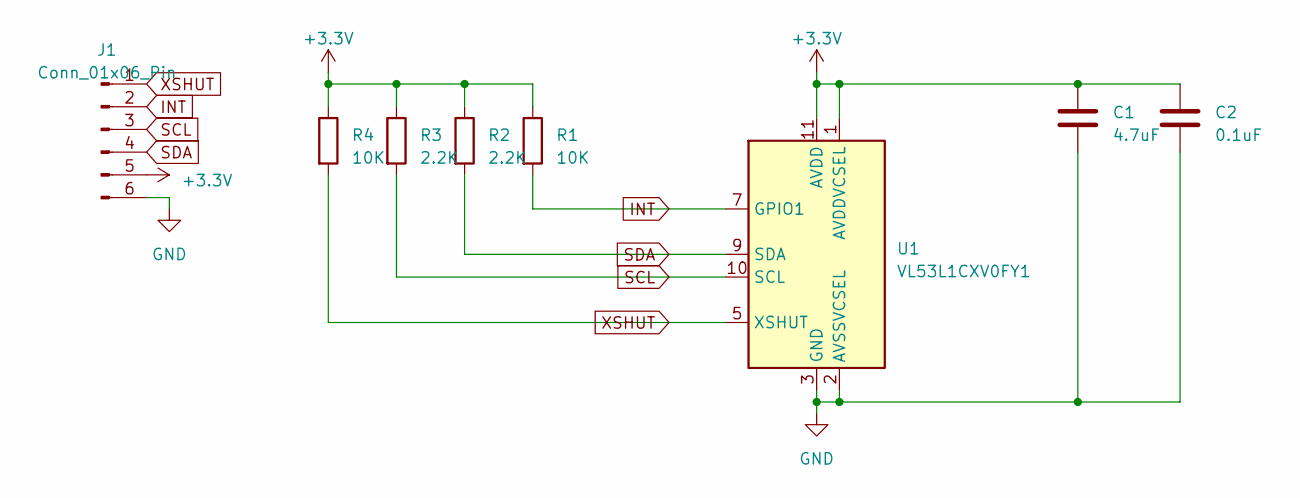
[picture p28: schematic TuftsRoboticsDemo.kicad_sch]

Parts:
C1: 4.7uF; C_0603_1608Metric
C2: 0.1uF; C_0603_1608Metric
J1: Conn_01x06_Pin; PinHeader_1x06_P2.54mm_Vertical
R1, R4: 10K; R_0603_1608Metric
R2, R3: 2.2K; R_0603_1608Metric
U1: VL53L1CXV0FY1; ST_VL53L1x

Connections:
+3.3V: C1.1, C2.1, J1.5, R1.1, R2.1, R3.1, R4.1, U1.1 (AVDDVCSEL), U1.11 (AVDD)
GND: C1.2, C2.2, J1.6, U1.2 (AVSSVCSEL), U1.3 (GND), U1.4 (GND), U1.6 (GND), U1.12 (GND)
INT: J1.2, R1.2, U1.7 (GPIO1)
SCL: J1.3, R3.2, U1.10 (SCL)
SDA: J1.4, R2.2, U1.9 (SDA)
XSHUT: J1.1, R4.2, U1.5 (XSHUT)

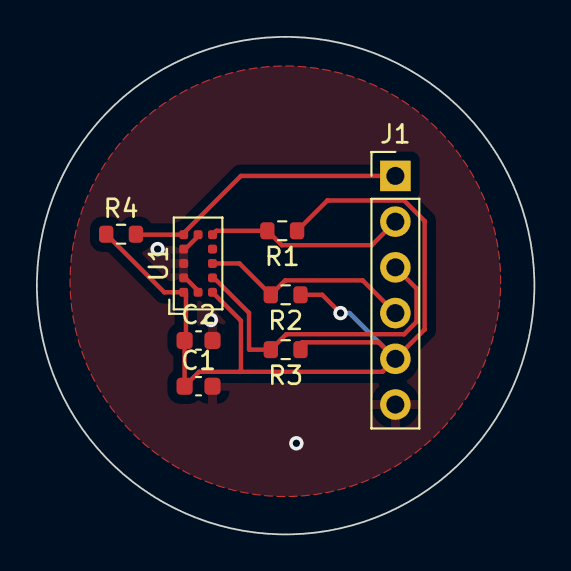
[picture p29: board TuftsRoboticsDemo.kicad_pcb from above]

Board: 2 copper layers, 27.6 x 27.6 mm, 8 parts (0 on the bottom side), 6 nets.

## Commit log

2023-04-16 Initial Files
    [KeyboardPCBWorkshop.kicad_pcb, KeyboardPCBWorkshop.kicad_sch]
2023-04-16 Tufts Robotics Reference
    [TuftsRoboticsDemo.kicad_pcb, TuftsRoboticsDemo.kicad_sch]
2023-04-16 ai03 MX/Alps switch footprint library
2023-04-16 ai03 usb c connectors and random parts
2023-04-17 update breakout PCB
    [KeyboardPCBWorkshop.kicad_pcb, KeyboardPCBWorkshop.kicad_sch, TuftsRoboticsDemo.kicad_pcb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]
2023-04-17 PCB update
2023-04-18 remove extraneous tufts robotics demo
    [TuftsRoboticsDemo.kicad_pcb, TuftsRoboticsDemo.kicad_sch]
2023-04-18 added XTAL, coupling cap, ISP header
    [KeyboardPCBWorkshop.kicad_sch]
2023-04-18 Added reset circuit and USB port
    [KeyboardPCBWorkshop.kicad_sch]
2023-04-18 keyboard matrix
    [KeyboardPCBWorkshop.kicad_sch]
2023-04-19 completed switch matrices
    [KeyboardPCBWorkshop.kicad_sch]
2023-04-19 footprint libraries connected
    [KeyboardPCBWorkshop.kicad_pcb, KeyboardPCBWorkshop.kicad_sch]
2023-04-19 assigned footprints
    [KeyboardPCBWorkshop.kicad_sch]
2023-04-19 Additional PCB changes
    [KeyboardPCBWorkshop.kicad_pcb, KeyboardPCBWorkshop.kicad_sch]
2023-04-20 routing complete
    [KeyboardPCBWorkshop.kicad_sch, PreGroundFill-KeyboardPCBWorkshop.kicad_pcb]
2023-04-20 FINISHED w/ERRORS?
    [KeyboardPCBWorkshop.kicad_pcb, PreGroundFill-KeyboardPCBWorkshop.kicad_pcb]
2023-04-20 rough draft of PCB guide
2023-04-20 Final Commit Before Workshop
    [KeyboardPCBWorkshop.kicad_pcb, PreGroundFill-KeyboardPCBWorkshop.kicad_pcb]
